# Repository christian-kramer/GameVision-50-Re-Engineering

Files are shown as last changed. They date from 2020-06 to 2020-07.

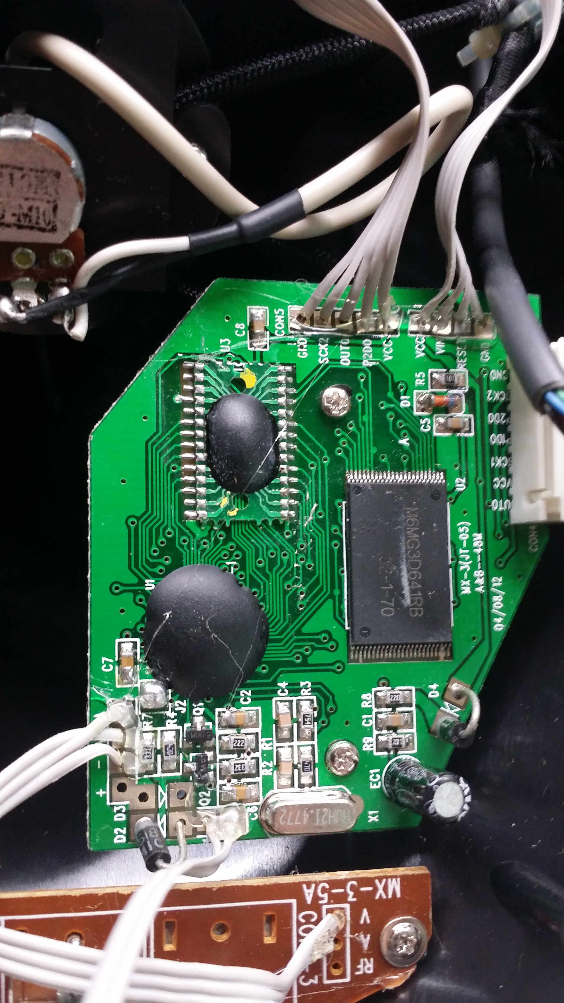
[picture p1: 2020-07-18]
Images/20200601_112341.jpg

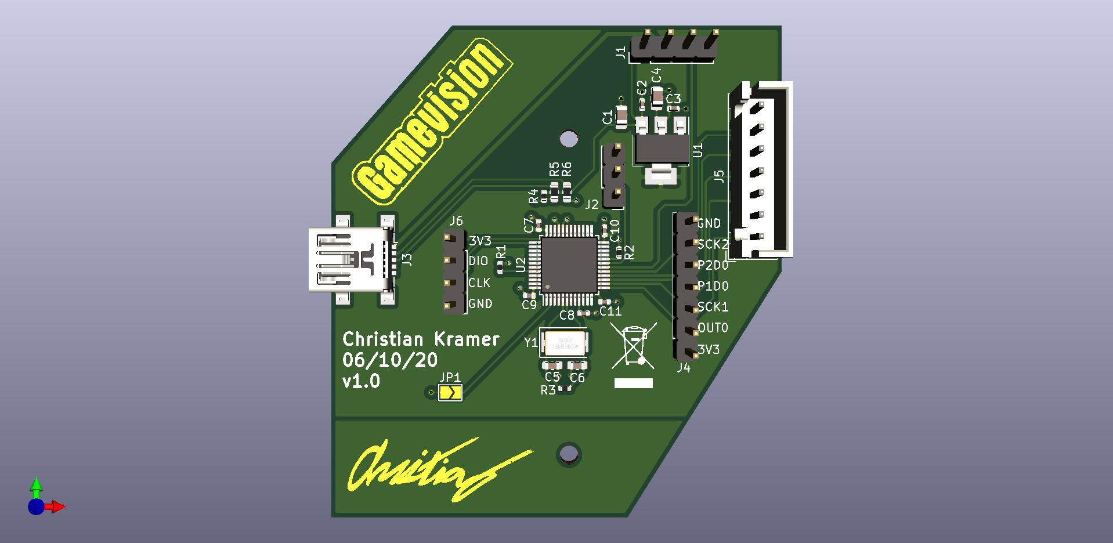
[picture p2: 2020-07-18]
Images/PCB Top View.jpg

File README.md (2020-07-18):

# GameVision-50-Re-Engineering
Turning a bizarre Russian/Taiwanese NES clone into something useful.
___

I've been definitely been looking in strange places for personal projects to do, lately. During my search I stumbled upon an old all-in-one game console/controller I used to play with when I was young.

This project is a continuation and implementation of my [STM32F103C8T6-Familiarization repo](https://github.com/christian-kramer/STM32F103C8T6-Familiarization)

GameVision 50

It's called the **GameVision 50**, presumably because it has 50 games.

Loading

Here is the full list of games, in case anyone recognizes one.

Page 1
Page 2
Page 3
Page 4

And, as an example, here's "Truck Race":

Truck Race

The games aren't exactly sophisticated... not quite the level of immersion I'm looking for. The wheel is nice, though. I wonder how hard it would be to adapt it for use with a PC?

Let's open it up and have a look.

Opened

Seems a lot less complicated than I thought it would be, actually. Let's take a closer look at that mainboard.

Close-up

Interesting layout, for sure. The big chip on the right is almost certainly a parallel flash IC, the chip-on-board in the lower-left is probably the main game processor (more on that in a bit), and quite honestly I have no idea what the "chip-on-board, on-board" thing in the top left is. It's gotta be a coprocessor of some sort, because it's thoroughly interconnected with both the game chip, and the flash chip. A converter between parallel flash and whatever interface the game processor requires, perhaps?

I'm interested in that connector on the far right of the board. It definitely doesn't appear to be a multiplexed analog button arrangement... the pin names like "SCK1", "OUT0", and "VCC" seem to indicate we've got some other device at the other end of this cable speaking a serial data language. I have never heard of "OUT0" in any serial data protocol I've worked with.

I googled some of these pinout names, and the first result on Google was [this webpage](http://xn----ctbgeuhdtdb2b.xn--p1ai/price/dendy/?parts&d=DW-MH-3):

Webpage

Woah! That's a lot of Russian. I can read some Russian, but not stuff that's this technical.

Translated

That's better. Looks like it's actually pretty straightforward. Dendy DW-MH-3? I've never heard of the company "Dendy Processors" before. I really want to know more about this chip.

Googling the company "Dendy Processors" led me to this Wikipedia page:

Dendy Page

Holy cow! "Dendy" was actually a Soviet NES clone! This project just got *really* interesting. I guess technically now I'm reverse-engineering 80's-vintage Soviet tech.

This makes a lot of sense now, because studying the board more I notice the oscillator's frequency is very familiar:

oscillator

The frequency indicated on this oscillator is 21.4772 MHz... Check out what we get when we google this frequency.

results

It's all NES/SNES stuff! Ha!

That last link is interesting, too. The *reason* 21.4772 MHz is used is because that's the sample rate for 525-line B-MAC video encoding.

BMAC

70's/80's video encoding standards are absolutely fascinating, and I highly encourage you to explore this rabbit hole if you're interested. The Wikipedia article on B-MAC  is a great starting point with tons of links that will take you further.

Wikipedia

Back to the project at hand! The Russian Dendy documentation page indicates VCC gets +5v, OUT0 is a common clock, SCK1 and SCK2 are clocks specific to each controller, and P1D0/P2D0 are the lines that the controllers transmit data on.

I've got a logic analyzer I can hook up to this and see if I can recognize a pattern.

Logic Analyzer

Next, let's fire it up and press some buttons!

Output

The top line is SCK1, and the next line down is P1D0. Looks like we've got a 2-byte "packet" clocked out by SCK1, with a little bit of a pause separating them. I'm curious, though... The webpage mentioned that OUT0 is a "common clock"... What does its output look like?

OUT0

Ah, okay! OUT0 appears to delineate each byte. It also looks like no matter which button I press on the wheel, both bytes are identical. I wonder if this is some crude error-checking going on?

Also, interestingly enough, this output is from the wheel being turned all the way to the left, meaning that although there's a potentiometer attached to the steering column, there is no analog data coming back to the Dendy chip... turning the wheel is functionally equivalent to pressing the left or right d-pad buttons! This will need to be rewired if we want this to function as an analog axis.

At this point, I think I'm comfortable enough with the Dendy controller protocol to try hooking this up to an STM32 Blue Pill.

Blue Pill

What you see here is the steering wheel controller of the GameVision 50 bypassing the original mainboard and communicating entirely with the STM32. Interestingly, it's able to interface directly with the STM32 without level-shifting because STM32 inputs are 5v tolerant, and 3.3v is above the TTL "logic high" threshold. The potentiometer on the breadboard is a stand-in for the one that's built-in to the steering column. I'll use that potentiometer in the final version.

After I got it talking with my PC and being recognized as a "Game Pad" in Windows with a single "steering" axis, it was time to take this rat's nest of wiring and turn it into a PCB!

PCB

I decided to keep the same shape and general layout as the original mainboard so that it may be a drop-in replacement/conversion. It felt much more professional, that way. Additionally, I broke out the steering wheel connector into test-points so that I may easily connect my logic analyzer in the event that I needed to debug my firmware in the future. The header for that is labeled J4, to the left of J5: the controller connector.

Delivered PCB

When the boards finally arrived, I was ecstatic about how they turned out! The "Gamevision" logo looks amazing, and all of the tiny capacitors and resistors were soldered perfectly. I opted to have the surface-mount components assembled at the factory due to the amount of fine-pitch soldering I would otherwise have to do myself. The only surface-mount component the factory couldn't do was the USB port, which was easy enough for me to hand-solder.

Side-by-side

Here you can see my board (left) vs. the old board (right). You can see how similar they are physically, but it also really gives you an idea of just how much more component-dense the old board is compared to mine. Lots of analog signals going on over there!

Layered

Here's another comparison view showing how I incorporated the existing JST-XH-7 connector into my design. Because I retained the same connector in the same location, the wheel plugs right in like it was made for it!

Empty

Now, to tackle this empty shell. That potentiometer in the middle will need to be reworked in order to work the way I want it to. Let's take a closer look to see why.

close-up

Right now there's a big ol' glob of solder connecting the wiper pin with ground, making the potentiometer act like a variable resistor. This is then hooked up to the wheel's control board, which senses if the wheel is turned left or right, and registers a "left" or "right" button-press accordingly.

This doesn't work for what we want it to do! We want to measure *how far* the wheel is turned left or right, not "if". For that, we need to connect this potentiometer up to the  PCB directly so the STM32 can read the analog signal, and not the wheel. But, if we disconnect the potentiometer from the two wires and just leave them hanging, we'll forever get a "right" button press due to the infinite resistance!

We need to trick the wheel into thinking the potentiometer is always in the center. I measured 4.7KΩ across the potentiometer in the "center" positon, so an approximately 4.7KΩ fixed resistor soldered to the wires should be a perfect stand-in.

Junk resistor

I had this resistor sitting in my "loose parts" bowl on my workbench. It measured something like 3.7KΩ, so close enough. After I soldered it on... no more "right" button press coming from the controller!

Put Together

Lastly, here it is all assembled. I repurposed the 3-wire Audio/Video ribbon cable for the potentiometer, and it all works great! Steering is super smooth, and all of the buttons work!

I'm glad I incorporated the test-point pin header, next to the controller connector. Initially, during writing the firmware, I was getting some weird data I had never encountered before. When I pressed a button, my PC indicated many other buttons being pressed as well! To me, this looked like a timing issue... But I wasn't entirely sure where in my program the issue could be. Being able to easily connect a logic analyzer to inspect my signals allowed me to easily pinpoint the issue of "**P1D0**" not being pulled back up to +5V! This "floating" appeared as additional button presses to the STM32. Enabling the STM32's internal pull-up resistor on that pin in software allowed me to fix the issue without even needing a hardware fix.

After that, I closed it up and loaded up some games to try it out with!

Here is a video of me showing the wheel in action, playing Euro Truck Simulator 2:

[https://i.imgur.com/FMJOuTz.mp4](https://i.imgur.com/FMJOuTz.mp4)

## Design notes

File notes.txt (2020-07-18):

http://xn----ctbgeuhdtdb2b.xn--p1ai/price/dendy/?parts&d=DW-MH-3

1. Open console
2. Google pin names
3. DW-MH-3 http://xn----ctbgeuhdtdb2b.xn--p1ai/price/dendy/?parts&d=DW-MH-3
4. Dendy Console https://en.wikipedia.org/wiki/Dendy_(console)

https://dl3.pushbulletusercontent.com/ZLbrwJPoP9Q7nNgH2fFISxheJo8OG3El/temp.png

https://dl3.pushbulletusercontent.com/ZetwpJihSo75LvyZ02aG3gFb86TO28rc/temp.png

5. Probe pins, OUT0 SCK P1D0
6. Write down codes for each button, realize there's some that share codes

Step voltage up to 5v on steering wheel, increase timing

Document "turbo" buttons

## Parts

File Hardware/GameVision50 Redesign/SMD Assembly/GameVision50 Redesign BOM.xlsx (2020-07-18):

Comment | Designator | Footprint | LCSC
10μF | C1,C4 | Capacitor_SMD:C_0805_2012Metric | C15850
20pF | C5,C6 | Capacitor_SMD:C_0603_1608Metric | C1648
100nF | C7,C9,C8,C10,C2,C3,C11 | Capacitor_SMD:C_0402_1005Metric | C1525
Reset/Power | J1 | Connector_PinHeader_2.54mm:PinHeader_1x04_P2.54mm_Vertical
Potentiometer | J2 | Connector_PinHeader_2.54mm:PinHeader_1x03_P2.54mm_Vertical
USB_B_Mini | J3 | Connector_USB:USB_Mini-B_Lumberg_2486_01_Horizontal
Test Points | J4 | Connector_PinHeader_2.54mm:PinHeader_1x07_P2.54mm_Vertical
Controller | J5 | Connector_JST:JST_XH_B7B-XH-A_1x07_P2.50mm_Vertical
STLink | J6 | Connector_PinHeader_2.54mm:PinHeader_1x04_P2.54mm_Vertical
Control Mode | JP1 | Jumper:SolderJumper-2_P1.3mm_Open_TrianglePad1.0x1.5mm
100KΩ | R1,R2 | Resistor_SMD:R_0402_1005Metric | C25741
1M | R3 | Resistor_SMD:R_0402_1005Metric | C26083
1.5KΩ | R4 | Resistor_SMD:R_0402_1005Metric | C25867
20Ω | R5,R6 | Resistor_SMD:R_0603_1608Metric | C22950
AMS1117-3.3 | U1 | Package_TO_SOT_SMD:SOT-223-3_TabPin2 | C6186
STM32F103C8Tx | U2 | Package_QFP:LQFP-48_7x7mm_P0.5mm | C8734
8MHz | Y1 | Crystal:Crystal_SMD_5032-2Pin_5.0x3.2mm | C115962

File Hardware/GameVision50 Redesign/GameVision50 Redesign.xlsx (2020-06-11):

value | footprint | datasheet | fields/field/0/_name | fields/field/0/__text | libsource/_lib | libsource/_part | libsource/_description | sheetpath/_names | sheetpath/_tstamps | tstamp | _ref
STM32F103C8Tx | Package_QFP:LQFP-48_7x7mm_P0.5mm | http://www.st.com/st-web-ui/static/active/en/resource/technical/document/datasheet/CD00161566.pdf | LCSC | C8734 | MCU_ST_STM32F1 | STM32F103C8Tx | ARM Cortex-M3 MCU, 64KB flash, 20KB RAM, 72MHz, 2-3.6V, 37 GPIO, LQFP-48 | / | / | 5ED930E6 | U2
Reset/Power | Connector_PinHeader_2.54mm:PinHeader_1x04_P2.54mm_Vertical | ~ |  |  | Connector_Generic | Conn_01x04 | Generic connector, single row, 01x04, script generated (kicad-library-utils/schlib/autogen/connector/) | / | / | 5ED971E4 | J1
Potentiometer | Connector_PinHeader_2.54mm:PinHeader_1x03_P2.54mm_Vertical | ~ |  |  | Connector_Generic | Conn_01x03 | Generic connector, single row, 01x03, script generated (kicad-library-utils/schlib/autogen/connector/) | / | / | 5ED97ED5 | J2
8MHz | Crystal:Crystal_SMD_5032-2Pin_5.0x3.2mm | ~ | LCSC | C115962 | Device | Crystal_Small | Two pin crystal, small symbol | / | / | 5EDCB5EE | Y1
1M | Resistor_SMD:R_0402_1005Metric | ~ | LCSC | C26083 | Device | R_Small | Resistor, small symbol | / | / | 5EDD1C24 | R3
20pF | Capacitor_SMD:C_0603_1608Metric | ~ | LCSC | C1648 | Device | C_Small | Unpolarized capacitor, small symbol | / | / | 5EDD5E12 | C5
20Ω | Resistor_SMD:R_0603_1608Metric | ~ | LCSC | C22950 | Device | R_Small | Resistor, small symbol | / | / | 5EDDAA2D | R5
20Ω | Resistor_SMD:R_0603_1608Metric | ~ | LCSC | C22950 | Device | R_Small | Resistor, small symbol | / | / | 5EDDBCA6 | R6
1.5KΩ | Resistor_SMD:R_0402_1005Metric | ~ | LCSC | C25867 | Device | R_Small | Resistor, small symbol | / | / | 5EDE1DF0 | R4
USB_B_Mini | Connector_USB:USB_Mini-B_Lumberg_2486_01_Horizontal | ~ |  |  | Connector | USB_B_Mini | USB Mini Type B connector | / | / | 5EDEE38F | J3
Controller | Connector_JST:JST_XH_B7B-XH-A_1x07_P2.50mm_Vertical | ~ |  |  | Connector_Generic | Conn_01x07 | Generic connector, single row, 01x07, script generated (kicad-library-utils/schlib/autogen/connector/) | / | / | 5ED952ED | J5
STLink | Connector_PinHeader_2.54mm:PinHeader_1x04_P2.54mm_Vertical | ~ |  |  | Connector_Generic | Conn_01x04 | Generic connector, single row, 01x04, script generated (kicad-library-utils/schlib/autogen/connector/) | / | / | 5ED98C94 | J6
100KΩ | Resistor_SMD:R_0402_1005Metric | ~ | LCSC | C25741 | Device | R_Small | Resistor, small symbol | / | / | 5EE38C0A | R1
100KΩ | Resistor_SMD:R_0402_1005Metric | ~ | LCSC | C25741 | Device | R_Small | Resistor, small symbol | / | / | 5EE3925C | R2
100nF | Capacitor_SMD:C_0402_1005Metric | ~ | LCSC | C1525 | Device | C_Small | Unpolarized capacitor, small symbol | / | / | 5EEB7BA9 | C7
100nF | Capacitor_SMD:C_0402_1005Metric | ~ | LCSC | C1525 | Device | C_Small | Unpolarized capacitor, small symbol | / | / | 5EEB8E8C | C9
100nF | Capacitor_SMD:C_0402_1005Metric | ~ | LCSC | C1525 | Device | C_Small | Unpolarized capacitor, small symbol | / | / | 5EEB92B7 | C8
100nF | Capacitor_SMD:C_0402_1005Metric | ~ | LCSC | C1525 | Device | C_Small | Unpolarized capacitor, small symbol | / | / | 5EEB98C2 | C10
Control Mode | Jumper:SolderJumper-2_P1.3mm_Open_TrianglePad1.0x1.5mm | ~ |  |  | Jumper | SolderJumper_2_Open | Solder Jumper, 2-pole, open | / | / | 5EEBB07A | JP1
20pF | Capacitor_SMD:C_0603_1608Metric | ~ | LCSC | C1648 | Device | C_Small | Unpolarized capacitor, small symbol | / | / | 5EEC84BE | C6
APX803S-29SA-7 | Package_TO_SOT_SMD:SOT-23 | http://ww1.microchip.com/downloads/en/DeviceDoc/11184d.pdf | LCSC | C143831 | Power_Supervisor | MCP130-xxxFxTO | Microcontroller supervisory circuit with internal 5 kΩ pull-up, TO-92 | / | / | 5EDAF659 | U3
4.7KΩ | Resistor_SMD:R_0402_1005Metric | ~ | LCSC | C25900 | Device | R_Small | Resistor, small symbol | / | / | 5EDB3C95 | R7
10μF | Capacitor_SMD:C_0805_2012Metric | ~ | LCSC | C15850 | Device | CP_Small | Polarized capacitor, small symbol | / | / | 5EDC44C0 | C1
100nF | Capacitor_SMD:C_0402_1005Metric | ~ | LCSC | C1525 | Device | C_Small | Unpolarized capacitor, small symbol | / | / | 5EE03D1D | C2
AMS1117-3.3 | Package_TO_SOT_SMD:SOT-223-3_TabPin2 | http://www.advanced-monolithic.com/pdf/ds1117.pdf |  |  | Regulator_Linear | AMS1117-3.3 | 1A Low Dropout regulator, positive, 3.3V fixed output, SOT-223 | / | / | 5EDBF4D0 | U1
100nF | Capacitor_SMD:C_0402_1005Metric | ~ | LCSC | C1525 | Device | C_Small | Unpolarized capacitor, small symbol | / | / | 5EEB74EE | C3
10μF | Capacitor_SMD:C_0805_2012Metric | ~ | LCSC | C15850 | Device | CP_Small | Polarized capacitor, small symbol | / | / | 5EEC946A | C4
100nF | Capacitor_SMD:C_0402_1005Metric | ~ | LCSC | C1525 | Device | C_Small | Unpolarized capacitor, small symbol | / | / | 5EDE028F | C11
Test Points | Connector_PinHeader_2.54mm:PinHeader_1x07_P2.54mm_Vertical | ~ |  |  | Connector_Generic | Conn_01x07 | Generic connector, single row, 01x07, script generated (kicad-library-utils/schlib/autogen/connector/) | / | / | 5EDC6B0E | J4

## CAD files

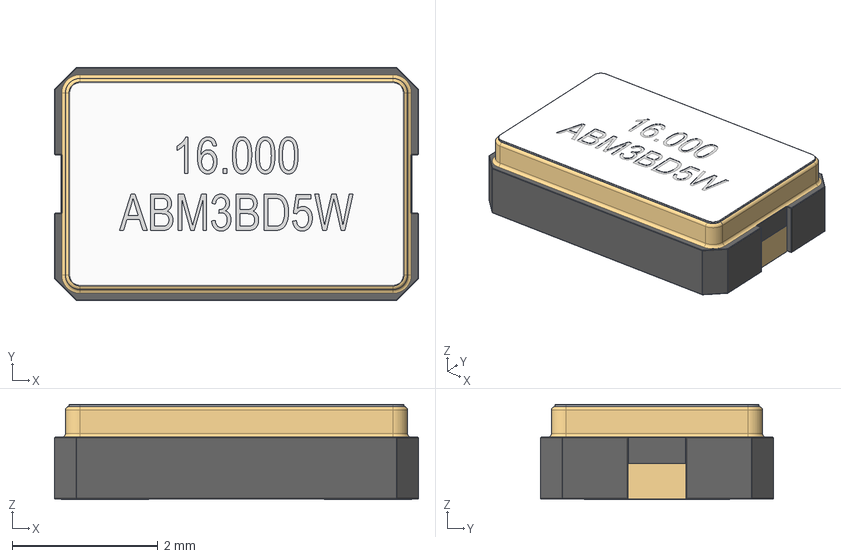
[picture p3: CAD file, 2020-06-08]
Hardware/GameVision50 Redesign/3D Models/Crystal ABM3-16.000MHZ-B2-T.stp
5.00 x 3.20 x 1.31 mm

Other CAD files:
Hardware/GameVision50 Redesign/3D Models/Crystal ABM3-16.000MHZ-B2-T.obj

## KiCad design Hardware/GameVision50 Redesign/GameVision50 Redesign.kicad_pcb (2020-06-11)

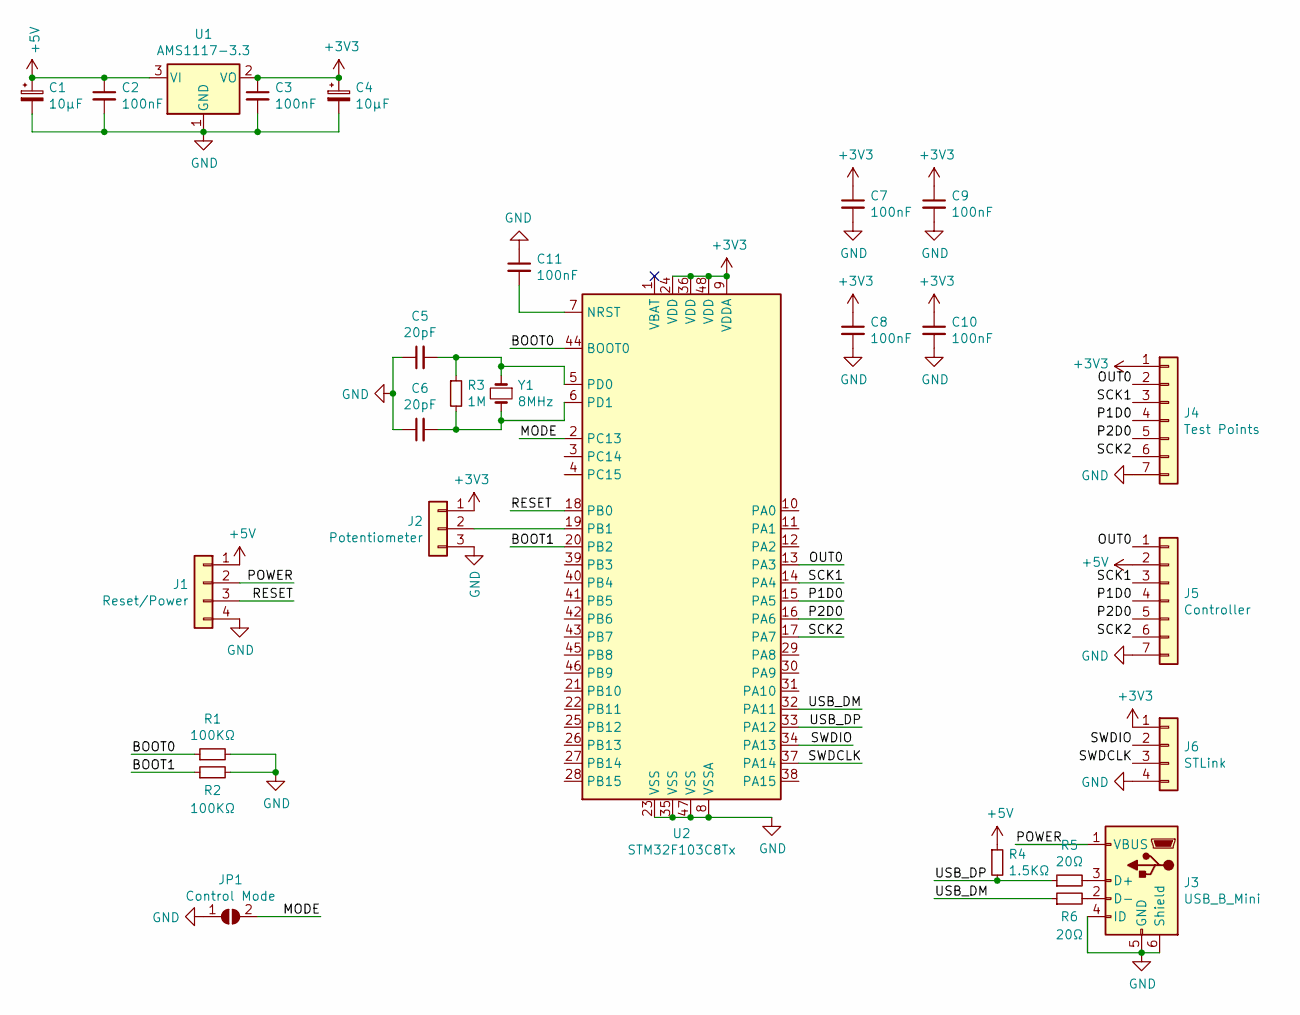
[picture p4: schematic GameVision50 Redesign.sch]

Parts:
C1, C4: 10μF; C_0805_2012Metric; LCSC C15850
C2, C3, C7, C8, C9, C10, C11: 100nF; C_0402_1005Metric; LCSC C1525
C5, C6: 20pF; C_0603_1608Metric; LCSC C1648
J1: Reset/Power; PinHeader_1x04_P2.54mm_Vertical
J2: Potentiometer; PinHeader_1x03_P2.54mm_Vertical
J3: USB_B_Mini; USB_Mini-B_Lumberg_2486_01_Horizontal
J4: Test Points; PinHeader_1x07_P2.54mm_Vertical
J5: Controller; JST_XH_B7B-XH-A_1x07_P2.50mm_Vertical
J6: STLink; PinHeader_1x04_P2.54mm_Vertical
JP1: Control Mode; SolderJumper-2_P1.3mm_Open_TrianglePad1.0x1.5mm
R1, R2: 100KΩ; R_0402_1005Metric; LCSC C25741
R3: 1M; R_0402_1005Metric; LCSC C26083
R4: 1.5KΩ; R_0402_1005Metric; LCSC C25867
R5, R6: 20Ω; R_0603_1608Metric; LCSC C22950
U1: AMS1117-3.3; SOT-223-3_TabPin2; LCSC C6186
U2: STM32F103C8Tx; LQFP-48_7x7mm_P0.5mm; LCSC C8734
Y1: 8MHz; Crystal_SMD_5032-2Pin_5.0x3.2mm; LCSC C115962

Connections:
+3V3: C3.1, C4.1, C7.1, C8.1, C9.1, C10.1, J2.1, J4.1, J6.1, U1.2 (VO), U2.9 (VDDA), U2.24 (VDD), U2.36 (VDD), U2.48 (VDD)
+5V: C1.1, C2.1, J1.1, J5.2, R4.1, U1.3 (VI)
/BOOT0: R1.1, U2.44 (BOOT0)
/BOOT1: R2.1, U2.20 (PB2)
/MODE: JP1.2 (B), U2.2 (PC13)
/OUT0: J4.2, J5.1, U2.13 (PA3)
/P1D0: J4.4, J5.4, U2.15 (PA5)
/P2D0: J4.5, J5.5, U2.16 (PA6)
/POWER: J1.2, J3.1 (VBUS)
/RESET: J1.3, U2.18 (PB0)
/SCK1: J4.3, J5.3, U2.14 (PA4)
/SCK2: J4.6, J5.6, U2.17 (PA7)
/SWDCLK: J6.3, U2.37 (PA14)
/SWDIO: J6.2, U2.34 (PA13)
/USB_DM: R6.1, U2.32 (PA11)
/USB_DP: R4.2, R5.1, U2.33 (PA12)
GND: C1.2, C2.2, C3.2, C4.2, C5.1, C6.1, C7.2, C8.2, C9.2, C10.2, C11.1, J1.4, J2.3, J3.4 (ID), J3.5 (GND), J3.6 (Shield), J4.7, J5.7, J6.4, JP1.1 (A), R1.2, R2.2, U1.1 (GND), U2.8 (VSSA), U2.23 (VSS), U2.35 (VSS), U2.47 (VSS)
unnamed: C5.2, R3.1, U2.5 (PD0), Y1.1
unnamed: C6.2, R3.2, U2.6 (PD1), Y1.2
unnamed: C11.2, U2.7 (NRST)
unnamed: J2.2, U2.19 (PB1)
unnamed: J3.2 (D-), R6.2
unnamed: J3.3 (D+), R5.2

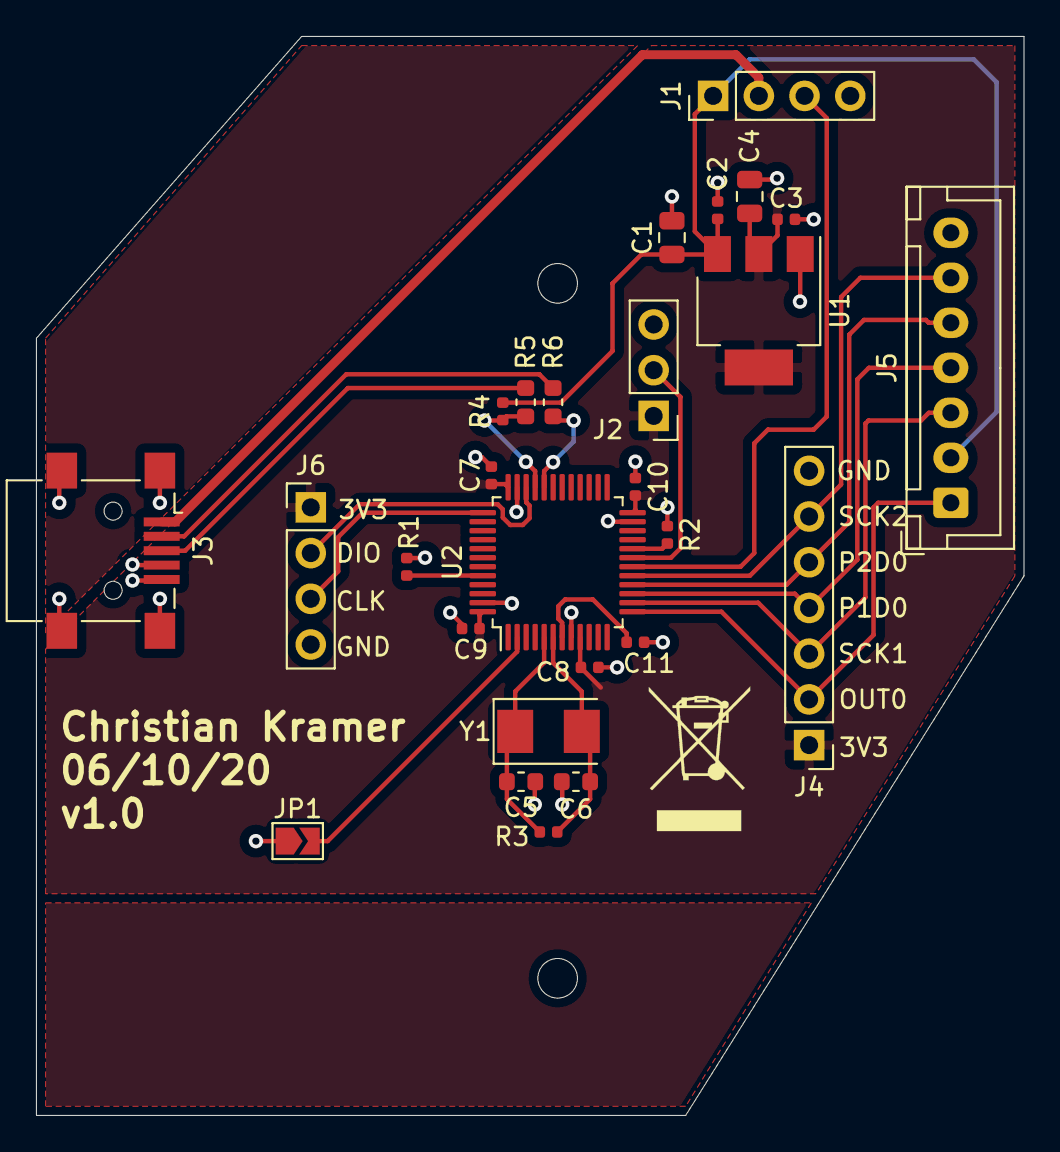
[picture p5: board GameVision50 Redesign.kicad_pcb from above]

Board: 2 copper layers, 54.9 x 59.9 mm, 27 parts (0 on the bottom side), 23 nets.

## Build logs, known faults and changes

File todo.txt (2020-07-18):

questions I have:

1. pull-up resistor on D+ to 5v, or 3.3v?
2. USB trace layout? Interference on ground plane?
3. oscillator layout?
4. analog trace for potentiometer layout? USB/8mhz oscillator interference?
5. 1M resistor on oscillator?
6. oscillator capacitor value/0403 size? other parameters I didn't consider?
7. 4.7k resistor on APX803S-29SA-7?
8. AMS1117 decoupling?

next steps:

1. export SMD assembly files in accordance with JLCPCB
2. add signature
3. add info
4. add board markings for no trash etc
5. add GameVision 50 logo
/6. create CubeMX project for pinout with labels
7. during which, manually follow every connection back to chip to ensure feasibilty for gpio/analog
8. check pinouts of headers and ensure they are accurate

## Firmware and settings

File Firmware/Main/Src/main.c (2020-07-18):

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

/* Includes ------------------------------------------------------------------*/
#include "main.h"
#include "usb_device.h"

/* USER CODE BEGIN Includes */
#include "stdbool.h"
#include "usbd_custom_hid_if.h"
extern USBD_HandleTypeDef hUsbDeviceFS;
/* USER CODE END Includes */

ADC_HandleTypeDef hadc1;

void SystemClock_Config(void);
static void MX_GPIO_Init(void);
static void MX_ADC1_Init(void);
/**
  * @brief  The application entry point.
  * @retval int
  */
int main(void)
{
  

  /* MCU Configuration--------------------------------------------------------*/

  /* Reset of all peripherals, Initializes the Flash interface and the Systick. */
  HAL_Init();

  /* Configure the system clock */
  SystemClock_Config();

  /* Initialize all configured peripherals */
  MX_GPIO_Init();
  MX_ADC1_Init();
  MX_USB_DEVICE_Init();
  /* USER CODE BEGIN 2 */

  uint16_t button_codes[8] = {
	  0b1000000010000000,
	  0b0100000001000000,
	  0b0010000000100000,
	  0b0001000000010000,
	  0b0000100000001000,
	  0b0000010000000100,
	  0b0000001000000010,
	  0b0000000100000001
  };

  struct gamepad_report_t
  {
	  uint16_t steering;
      uint16_t buttons;
  };

  bool clock_one_bit()
  {
	  bool result = HAL_GPIO_ReadPin(GPIOA, Controller_Data_Pin);
	  HAL_GPIO_WritePin(GPIOA, Controller_Clock_Pin, RESET); //-_
	  HAL_GPIO_WritePin(GPIOA, Controller_Clock_Pin, SET); //-_-
	  HAL_Delay(1);
	  return result;
  }

  uint16_t get_controller_register()
  {
	  uint16_t controller_register = 0;
	  uint8_t counter = 15;

	  //build 2 sets of 8 bits
	  for (uint8_t i = 0; i < 2; i++)
	  {
		  //global clock gets a pulse
		  HAL_GPIO_WritePin(GPIOA, Global_Clock_Pin, SET); //_-
		  HAL_GPIO_WritePin(GPIOA, Global_Clock_Pin, RESET); //_-_

		  //take a reading of first bit

		  for (uint8_t j = 0; j < 8; j++)
		  {
			  //clock out 8 bits
			  controller_register |= clock_one_bit() << counter--;
		  }
	  }
	  return ~controller_register;
  }

  //Setup default pin states for 3-pin controller

  HAL_GPIO_WritePin(GPIOA, Global_Clock_Pin, RESET);
  HAL_GPIO_WritePin(GPIOA, Controller_Clock_Pin, SET);

  /* USER CODE END 2 */

  /* Infinite loop */
  /* USER CODE BEGIN WHILE */
  while (1)
  {
	  struct gamepad_report_t gamepadReport;
	  //gamepadReport.buttons = 0;

	  HAL_ADC_Start(&hadc1);
	  HAL_ADC_PollForConversion(&hadc1, 100);

	  gamepadReport.steering = HAL_ADC_GetValue(&hadc1);

	  uint16_t controller_register = get_controller_register();
	  //gamepadReport.buttons = controller_register;

	  gamepadReport.buttons = 0;
	  for (int i = 0; i < (sizeof(button_codes) / 2); i++)
	  {
		  //gamepadReport.buttons |= 1 << i;
		  if (controller_register && controller_register & button_codes[i])
		  {
			  gamepadReport.buttons |= 1 << i;
		  }
	  }

	  //Handle "Reset" Button
	  if (HAL_GPIO_ReadPin(GPIOB, RESET_Pin) == 0)
	  {
		  gamepadReport.buttons |= 1 << 8;
	  }

	  USBD_CUSTOM_HID_SendReport(&hUsbDeviceFS, &gamepadReport, sizeof(struct gamepad_report_t));
    /* USER CODE END WHILE */

    /* USER CODE BEGIN 3 */
  }
  /* USER CODE END 3 */
}

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


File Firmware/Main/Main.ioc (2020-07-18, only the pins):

Mcu.UserName=STM32F103C8Tx
PA11.Signal=USB_DM
PA12.Signal=USB_DP
PA13.Signal=SYS_JTMS-SWDIO
PA14.Signal=SYS_JTCK-SWCLK
PA3.GPIO_Label=Global_Clock
PA3.Signal=GPIO_Output
PA4.GPIO_Label=Controller_Clock
PA4.Signal=GPIO_Output
PA5.GPIO_Label=Controller_Data
PA5.Signal=GPIO_Input
PA6.GPIO_Label=P2D0
PA6.Signal=GPIO_Input
PA7.GPIO_Label=SCK2
PA7.Signal=GPIO_Output
PB0.GPIO_Label=RESET
PB0.Signal=GPIO_Input
PB1.Signal=ADCx_IN9
PC13-TAMPER-RTC.GPIO_Label=Mode
PC13-TAMPER-RTC.Signal=GPIO_Input
PD0-OSC_IN.Signal=RCC_OSC_IN
PD1-OSC_OUT.Signal=RCC_OSC_OUT

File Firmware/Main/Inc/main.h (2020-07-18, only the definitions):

#define Mode_Pin GPIO_PIN_13
#define Mode_GPIO_Port GPIOC
#define Global_Clock_Pin GPIO_PIN_3
#define Global_Clock_GPIO_Port GPIOA
#define Controller_Clock_Pin GPIO_PIN_4
#define Controller_Clock_GPIO_Port GPIOA
#define Controller_Data_Pin GPIO_PIN_5
#define Controller_Data_GPIO_Port GPIOA
#define P2D0_Pin GPIO_PIN_6
#define P2D0_GPIO_Port GPIOA
#define SCK2_Pin GPIO_PIN_7
#define SCK2_GPIO_Port GPIOA
#define RESET_Pin GPIO_PIN_0
#define RESET_GPIO_Port GPIOB

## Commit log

2020-06-01 working steering and 16-button interface
2020-06-01 limited 16 button interface to 13 buttons
2020-06-02 Updated USB HID MID/PID
2020-06-02 working interface with PC with left thumb button
2020-06-03 fast, reliable working buttons and steering
2020-06-05 first version of kicad schematic prior to annotate
    [GameVision50 Redesign.kicad_pcb, GameVision50 Redesign.sch]
2020-06-05 annotated and assigned footprints
    [GameVision50 Redesign.sch]
2020-06-05 added power-on reset IC with pull-up and bypass cap
    [GameVision50 Redesign.sch]
2020-06-05 made edge cuts and mounting holes
2020-06-08 better footprint layout and 3d model of oscillator
    [Crystal ABM3-16.000MHZ-B2-T.obj, Crystal ABM3-16.000MHZ-B2-T.stp, GameVision50 Redesign.kicad_pcb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]
2020-06-11 exported version 1 of PCB to manufacture
    [GameVision50 Redesign-B_Cu.gbr, GameVision50 Redesign-B_Mask.gbr, GameVision50 Redesign-B_Paste.gbr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]
2020-07-18 updated to reflect current state of project
    [GameVision50 Redesign BOM.xlsx, GameVision50 Redesign Footprints.xlsx]

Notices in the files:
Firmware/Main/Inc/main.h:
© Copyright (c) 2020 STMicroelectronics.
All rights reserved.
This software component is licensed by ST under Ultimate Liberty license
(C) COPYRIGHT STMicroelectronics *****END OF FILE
